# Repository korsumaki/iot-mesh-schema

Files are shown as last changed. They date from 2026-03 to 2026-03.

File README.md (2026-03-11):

# iot-mesh-schema
Schematics and PCB for IoT sensor device

## Description

This PCB is used to connect Meshtastic Node with Wemos d1 mini arduino.

Temperature and humidity/pressure sensors are connected to Wemos.

Firmware for Wemos is  [arduino-iot-sensors](https://github.com/korsumaki/arduino-iot-sensors) repository.

## Board

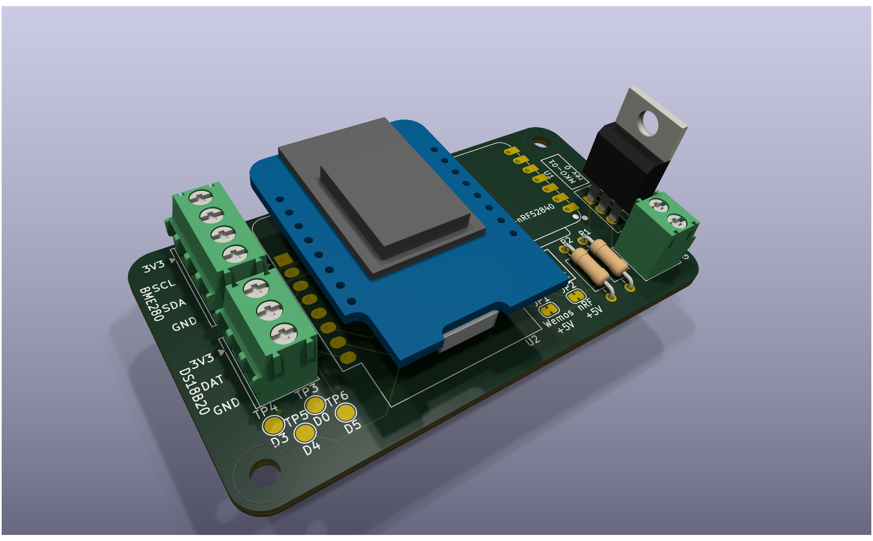
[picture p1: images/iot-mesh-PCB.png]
Rendered PCB image Rendered PCB


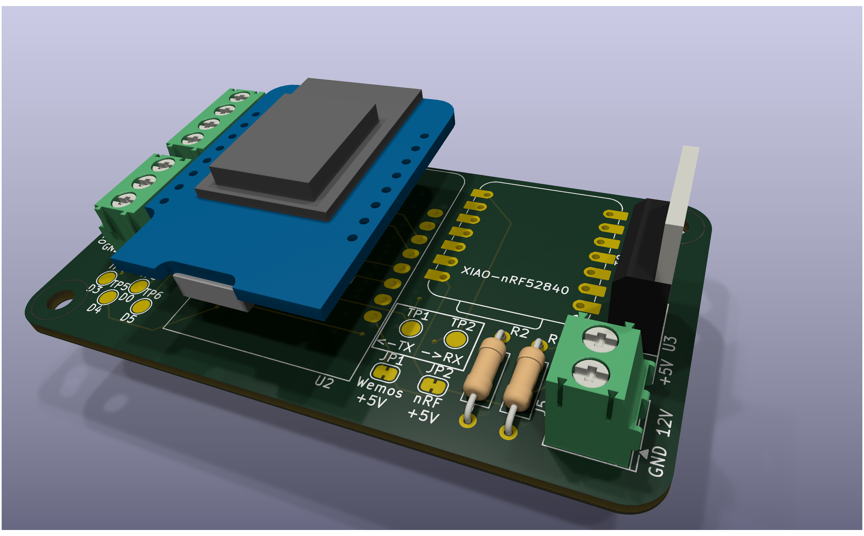
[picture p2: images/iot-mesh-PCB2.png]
Rendered PCB image Rendered PCB


## Schematics
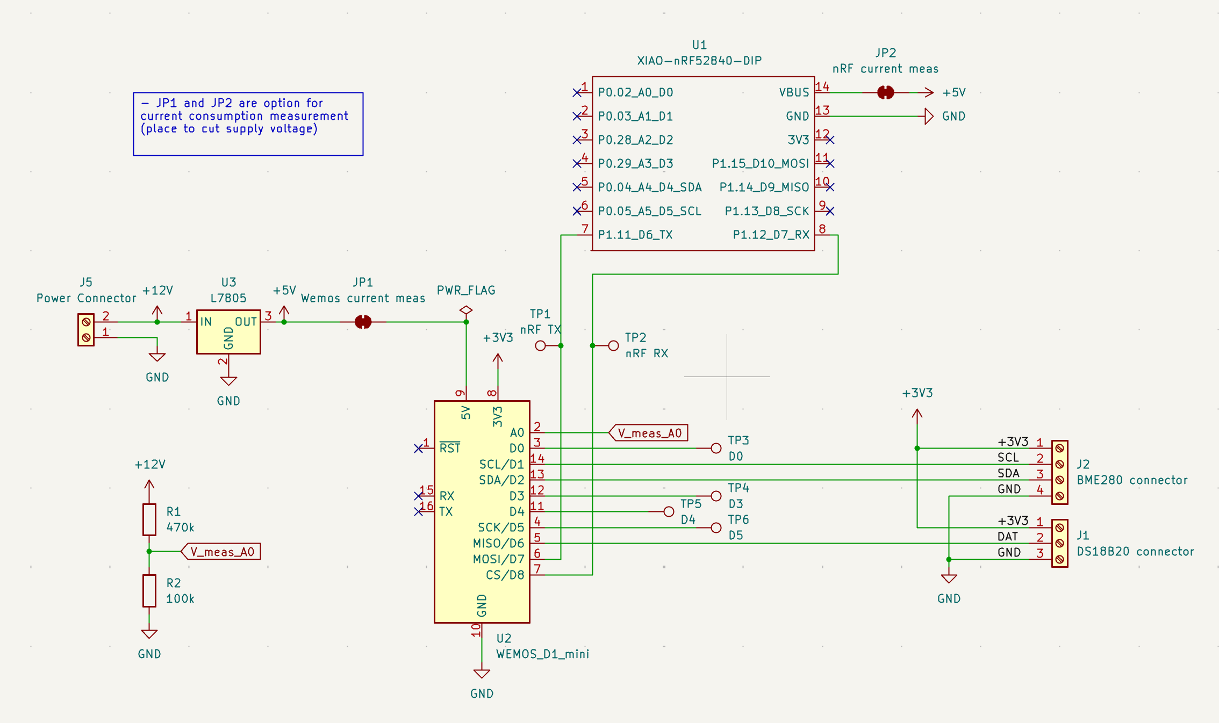
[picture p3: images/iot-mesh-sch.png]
Schematics


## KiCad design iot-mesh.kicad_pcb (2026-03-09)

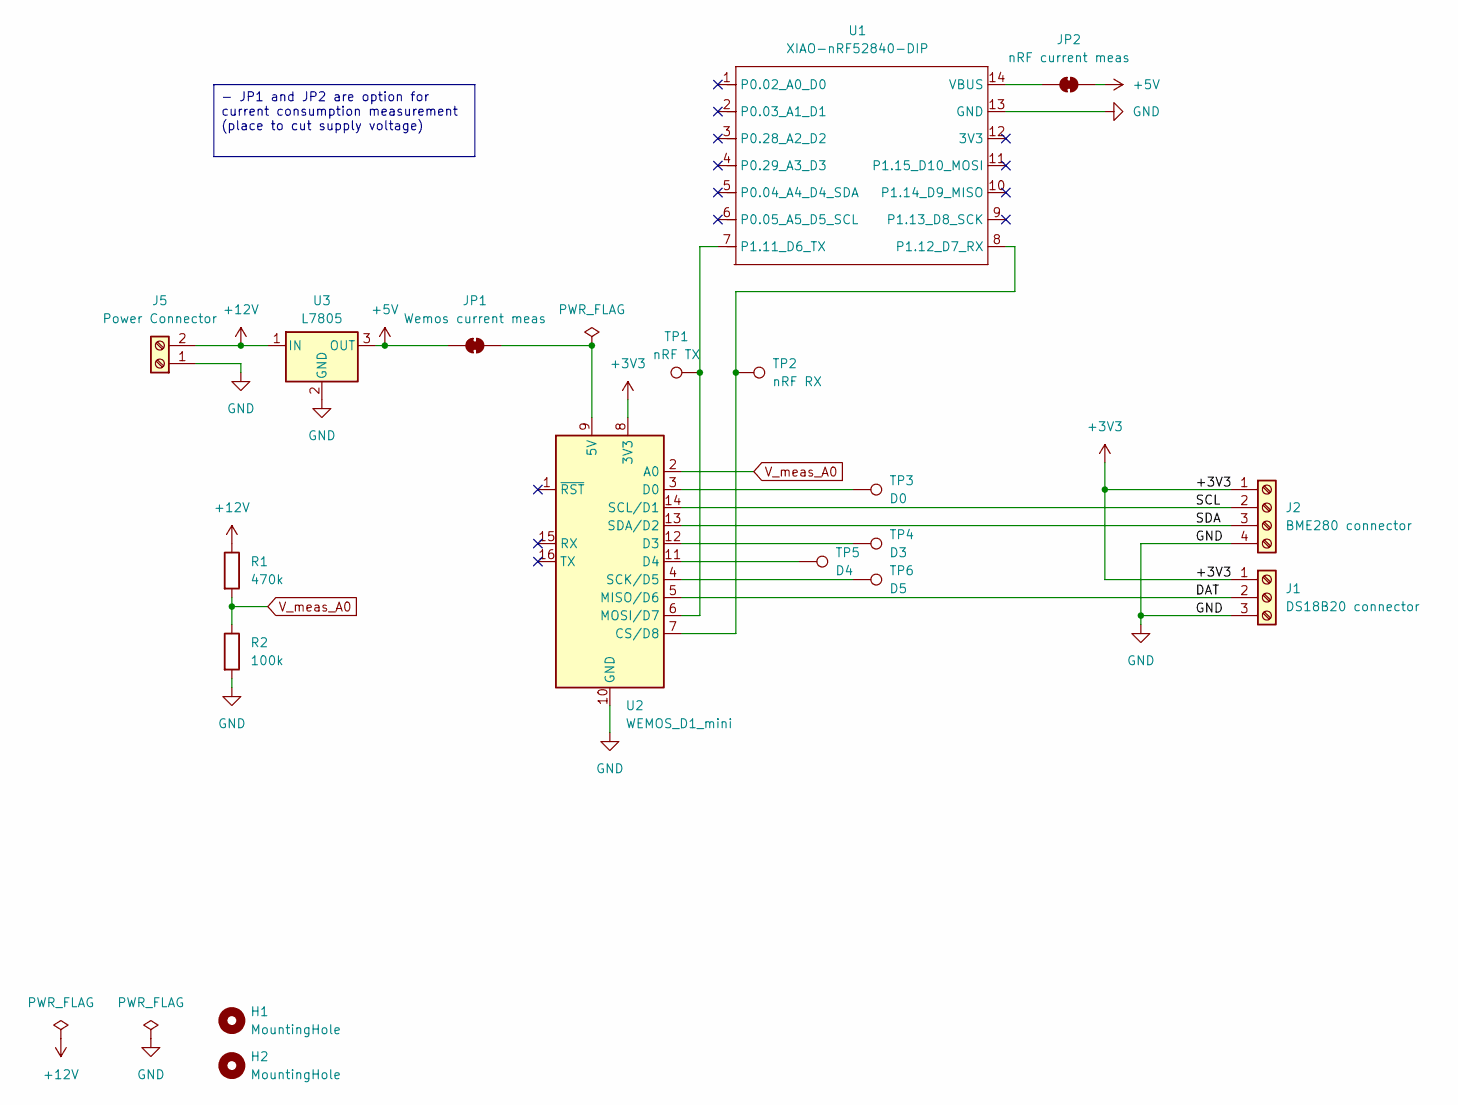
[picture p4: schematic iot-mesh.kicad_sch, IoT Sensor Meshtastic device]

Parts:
H1, H2: MountingHole; MountingHole_3.2mm_M3
J1: DS18B20 connector; TerminalBlock_Phoenix_PT-1,5-3-3.5-H_1x03_P3.50mm_Horizontal
J2: BME280 connector; TerminalBlock_Phoenix_PT-1,5-4-3.5-H_1x04_P3.50mm_Horizontal
J5: Power Connector; TerminalBlock_Phoenix_PT-1,5-2-3.5-H_1x02_P3.50mm_Horizontal
JP1: Wemos current meas; SolderJumper-2_P1.3mm_Bridged_RoundedPad1.0x1.5mm
JP2: nRF current meas; SolderJumper-2_P1.3mm_Bridged_RoundedPad1.0x1.5mm
R1: 470k; R_Axial_DIN0207_L6.3mm_D2.5mm_P10.16mm_Horizontal
R2: 100k; R_Axial_DIN0207_L6.3mm_D2.5mm_P10.16mm_Horizontal
TP1: nRF TX; TestPoint_Pad_D2.0mm
TP2: nRF RX; TestPoint_Pad_D2.0mm
TP3: D0; TestPoint_Pad_D2.0mm
TP4: D3; TestPoint_Pad_D2.0mm
TP5: D4; TestPoint_Pad_D2.0mm
TP6: D5; TestPoint_Pad_D2.0mm
U1: XIAO-nRF52840-DIP; XIAO-nRF52840-DIP-mk
U2: WEMOS_D1_mini; WEMOS_D1_mini_light
U3: L7805; TO-220-3_Vertical

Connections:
+3V3: J1.1, J2.1, U2.8 (3V3)
+5V: JP1.2 (B), JP2.2 (B), U3.3 (OUT)
+12V: J5.2, R1.1, U3.1 (IN)
/DAT: J1.2, U2.5 (MISO/D6)
/SCL: J2.2, U2.14 (SCL/D1)
/SDA: J2.3, U2.13 (SDA/D2)
GND: J1.3, J2.4, J5.1, R2.2, U1.13 (GND), U2.10 (GND), U3.2 (GND)
unnamed: JP1.1 (A), U2.9 (5V)
unnamed: JP2.1 (A), U1.14 (VBUS)
unnamed: TP1.1, U1.7 (P1.11_D6_TX), U2.6 (MOSI/D7)
unnamed: TP2.1, U1.8 (P1.12_D7_RX), U2.7 (CS/D8)
unnamed: TP3.1, U2.3 (D0)
unnamed: TP4.1, U2.12 (D3)
unnamed: TP5.1, U2.11 (D4)
unnamed: TP6.1, U2.4 (SCK/D5)
V_meas_A0: R1.2, R2.1, U2.2 (A0)

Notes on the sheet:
- JP1 and JP2 are option for current consumption measurement (place to cut supply voltage)

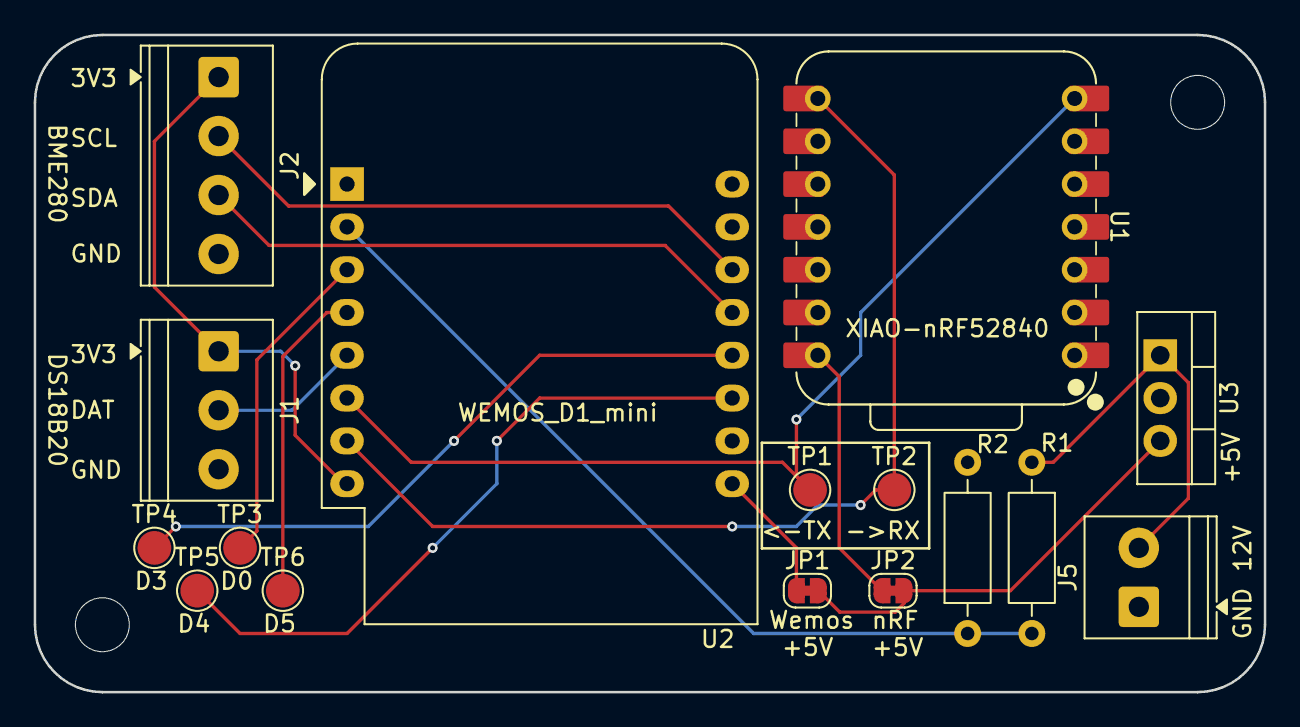
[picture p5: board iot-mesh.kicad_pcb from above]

Board: 2 copper layers, 73.0 x 39.0 mm, 18 parts (0 on the bottom side), 16 nets.

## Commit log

2026-03-03 First schematics and PCB version
    [iot-mesh.kicad_pcb, iot-mesh.kicad_sch]
2026-03-05 Add project specific symbol and footprint
    XIAO-nRF52840-DIP is modified so that silkscreen does not go over pads.
    [iot-mesh.kicad_pcb, iot-mesh.kicad_sch]
2026-03-05 Update title block
    [iot-mesh.kicad_pcb, iot-mesh.kicad_sch]
2026-03-05 Line width changes on silkscreen and edges
    [iot-mesh.kicad_pcb]
2026-03-09 Component selections and updates for preparing order
    [iot-mesh.kicad_pcb, iot-mesh.kicad_sch]
